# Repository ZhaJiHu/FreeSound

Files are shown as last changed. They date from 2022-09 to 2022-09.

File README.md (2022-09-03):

# FreeSound项目

本项目是我一次小的尝试，使用了扩音锥，360度发声音箱。使用D类功放和DSP，小体积大能量

**项目完全开源、任何人都可以根据本Github内容进行白嫖，也可以顺手点个Star**

## 介绍

本项目使用了威发的2.5寸全频喇叭，TPA3118 D类功放，ADAU1701 DSP，QCC5125。整体大小为8.3*15.3CM

项目成本<500RMB（自有3D打印机）

### 视频介绍：[https://www.bilibili.com/video/BV1xe4y1h7ed/?vd_source=25617b52e7e0b6d56790cc1bea5b5be1](https://www.bilibili.com/video/BV1xe4y1h7ed/?vd_source=25617b52e7e0b6d56790cc1bea5b5be1)

## 资料说明

- 3D模型设计文件
- 电源模块、音频模块、触摸模块硬件工程
- DSP程序文件和ESP32 BIN文件
- 各类文档和图片
- STL打印文件

## 结构设计

采用全向扩音锥设计，360度发声。为了提高低音，采用两个2寸对称式被动振膜。采用了大量3D打印件，打印的时候可调高填充率，震动会少点，emm，为了避免漏气的问题，最好补上热熔胶。顶部为了透光性，使用了透明的3M胶，给每个LED都单独设计了一个隔光栅格。

- 提供了一份完整的step设计文件

## 电路模块

### 电源模块：

- 电池使用2S锂电，使用TP5100充电模块，TYPE-C引电采用CH224K，默认引12V电
- 使用一颗ESP32，主要处理触摸输入，蓝牙输入，开关机，未来还可以与DSP通信，在线调音

### 音频模块

- 使用TPA3118 D类功放，7.4V供电
- 使用ADI ADAU1701 DSP IC，可使用USBi进行在线调参，也可以下载到EEPROM自启动
- 蓝牙采用QCC5125模块，输出I2S音频信号
- 使用SRC4192IDB间接输出MCLK给到DSP
- 使用FPC 蓝牙天线

### 触摸模块

- 使用BS814A-1触摸模块，为了得到最大的感应厚度，没有焊接对地电容
- 使用28颗WS2812B-2020

## 固件说明

本次由于时间关系，还没有整理好代码，因此先提供esp32的bin文件。DSP使用的是图形化编程，工程文件已提供，需要自行下载SigmaStudio

## 打样说明

### 3D打印：

- 文件位于：/6.Process**/3D打印，**该文件为STL格式，数量都是为1

### PCB打样

- 可以使用github内的工程文件导出Gerber文件，也可以使用提供好的Gerber文件，文件位于：/6.Process**/**Gerber

### BOM

- 在整理

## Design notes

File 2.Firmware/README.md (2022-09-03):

# README.md

- Dsp_FreeSound.dspproj
    - ADAU1701 DSP程序，请去ADI官网下载SigmaStudio 4.6打开
- firmware.bin
    - ESP32固件

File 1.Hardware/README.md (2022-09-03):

# README.md

- McuPower.zip
    - 电源板
- Sound.zip
    - 音频板
- Touch.zip
    - 触摸板
- 请用立创EDA专业版打开

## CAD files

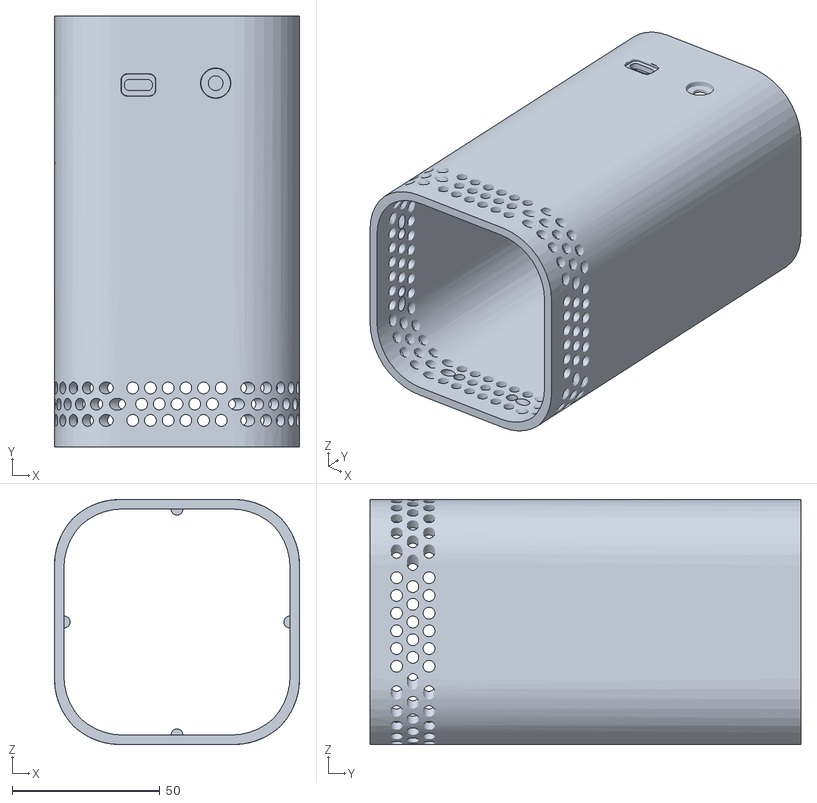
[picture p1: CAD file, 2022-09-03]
5.Process/3D打印/外框架子.STL
83.0 x 146.0 x 83.0

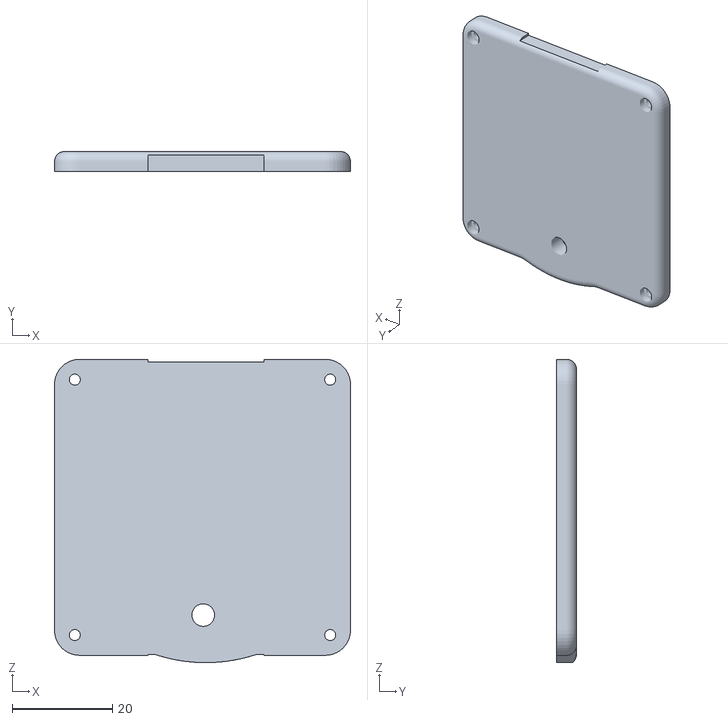
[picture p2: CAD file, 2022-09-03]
5.Process/3D打印/喇叭腔体盖板.STL
59.0 x 4.00 x 60.5

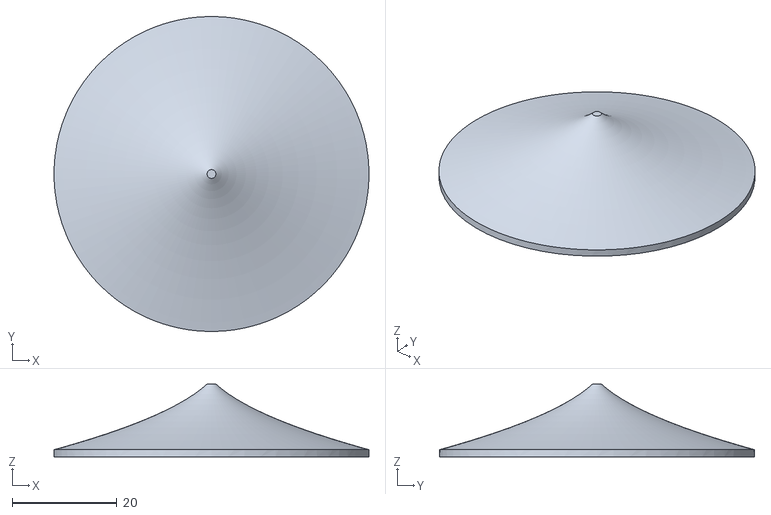
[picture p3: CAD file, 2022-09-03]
5.Process/3D打印/上盖_装配体 - 扩音锥.STL
60.2 x 60.2 x 13.9

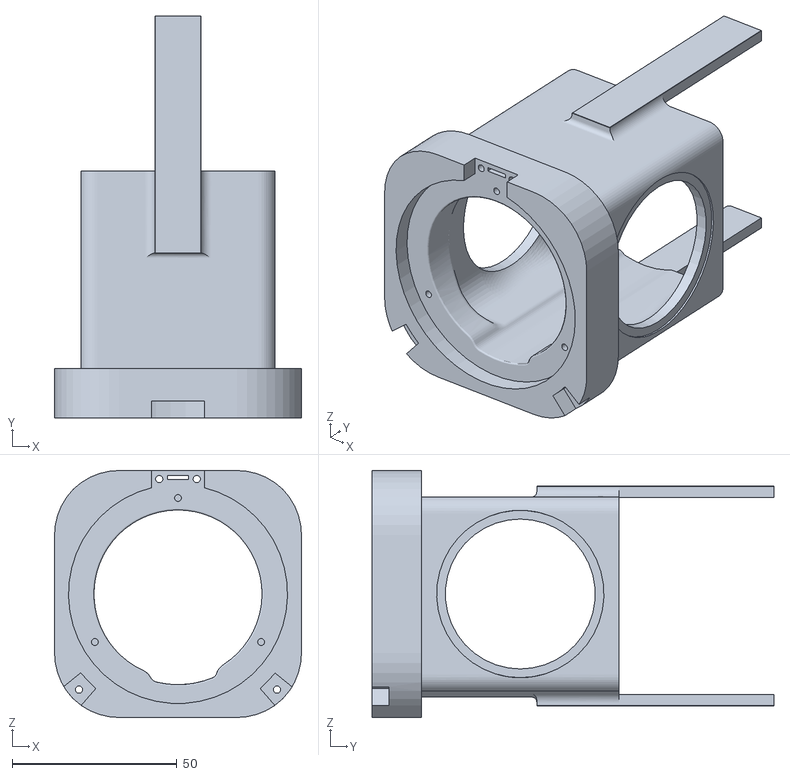
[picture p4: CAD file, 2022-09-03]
5.Process/3D打印/喇叭腔体.STL
75.0 x 122.0 x 75.0

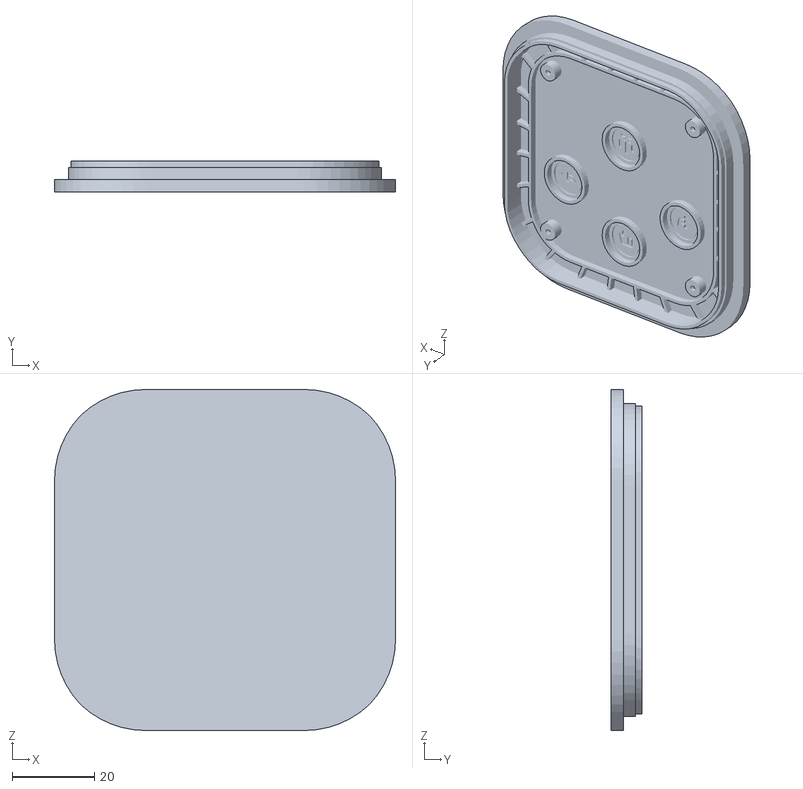
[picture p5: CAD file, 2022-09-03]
5.Process/3D打印/上盖_B.STL
83.0 x 7.50 x 83.0

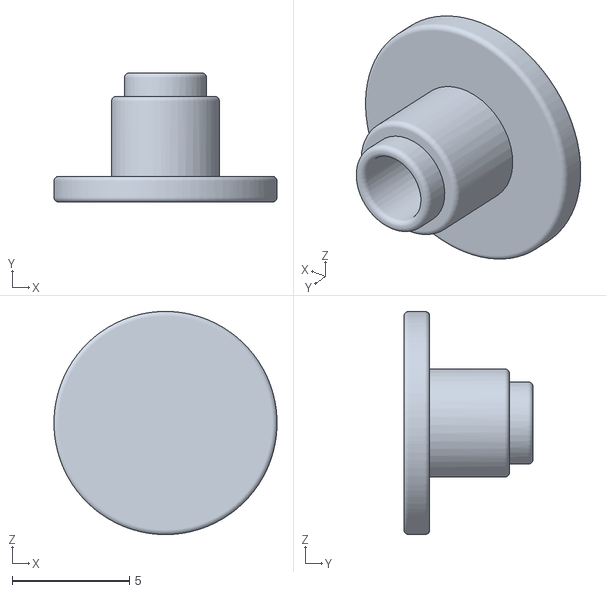
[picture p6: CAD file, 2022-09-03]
5.Process/3D打印/按钮.STL
9.49 x 5.50 x 9.50

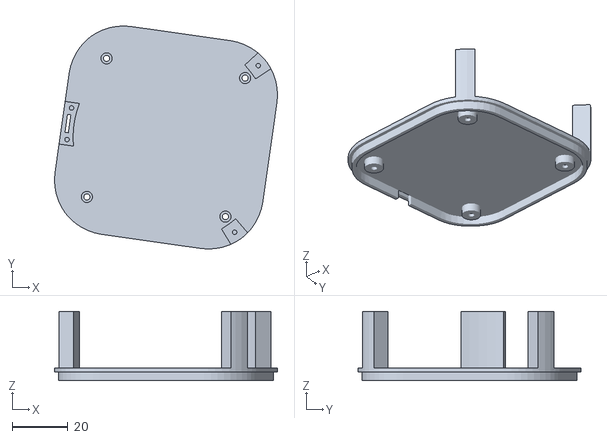
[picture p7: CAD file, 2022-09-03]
5.Process/3D打印/上盖_装配体 - 上盖_A-1.STL
79.7 x 79.7 x 24.7

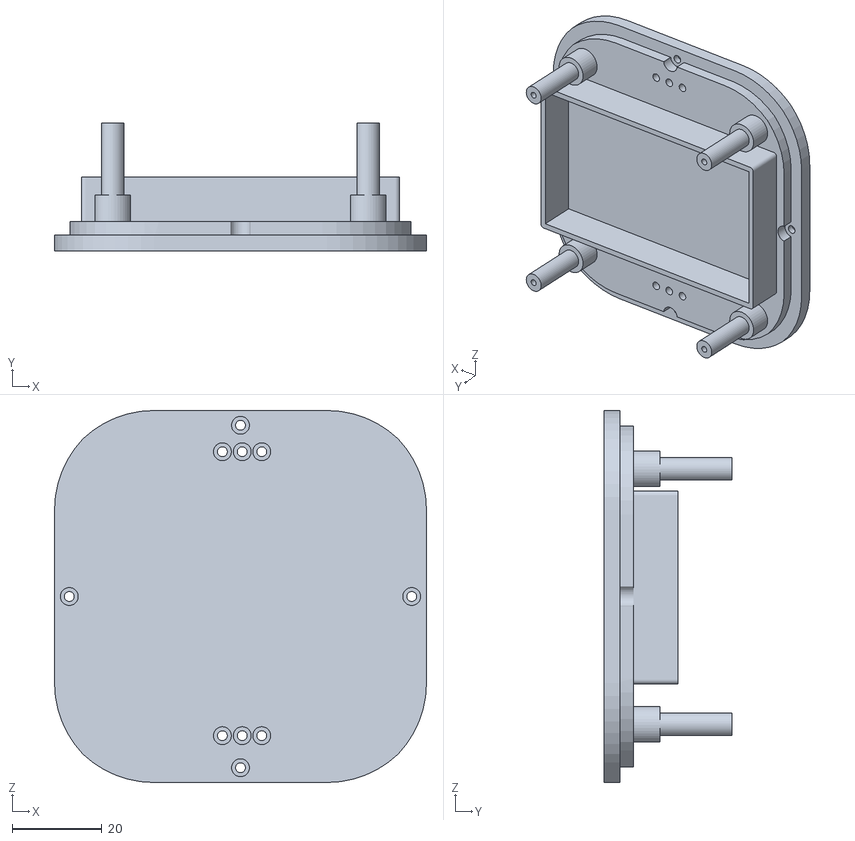
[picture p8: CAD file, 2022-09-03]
5.Process/3D打印/底座.STL
83.0 x 28.5 x 83.0
